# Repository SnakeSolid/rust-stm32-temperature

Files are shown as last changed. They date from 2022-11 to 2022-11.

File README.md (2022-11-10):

# Bluetooth Temperature Sensor

Read temperature, humidity and pressure from BME280 and write measurements to Bluetooth serial port. Serial output
example:

```
T: 23:87 C, P: 749.6 mmHg, H: 35.844%
T: 24:76 C, P: 749.6 mmHg, H: 34.101%
T: 24.70 C, P: 749.7 mmHg, H: 33.334%
```

Note: output rows are separated with `\n` new line sequence.

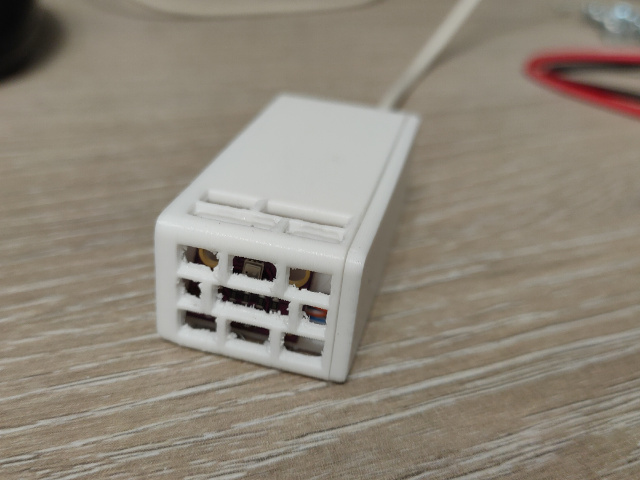
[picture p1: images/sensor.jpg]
Bluetooth sensor


### Wiring Diagram

Sensor BME280 use interface I2C2 (PA12, PA11), Bluetooth use interface USART2 (PA2, PA3). By default BME280 must be
available on address 0x76 (SDO connected to GND).

```
                                 STM32G030Fx (TSSOP20)
                        /-------------------------------------+
                      --| PB7/PB8           20PB3/PB4/PB5/PB6 |--
                      --| PB9/PC14-OSC32_IN   PA15/PA14-BOOT0 |--      to BME280
                      --| PC15-OSC32_OUT                 PA13 |--
                      --| VDD/VDDA                 PA12[PA10] |-- I2C2_SDA
                      --| VSS/VSSA                  PA11[PA9] |-- I2C2_SCL
                      --| NRST                PB0/PB1/PB2/PA8 |--
   to Bluetooth       --| PA0                             PA7 |--
                      --| PA1                             PA6 |--
            USART2_TX --| PA2                             PA5 |--
            USART2_RX --| PA3                             PA4 |--
                        +-------------------------------------+
```

### Build

By default cargo will use native build target. To build firmware for STM32G030 following command can be used:

```sh
cargo build --target thumbv6m-none-eabi --release
```

Command to connect to microcontroller using JTAG:

```sh
openocd -f openocd.cfg
```

Version of `openocd` utility must be greater or equals to `0.11.0`, earlier versions does not support STM32G030
microcontrollers. To flash and debug firmware use following command:

```sh
gdb-multiarch target/thumbv6m-none-eabi/release/stm32-bme280-temperature --command openocd.gdb
```

File `openocd.gdb` already contains commands to establish connection with `openocd`, enable semihosting, load firmware
and set breakpoints to `DefaultHandler` and `HardFault` handlers. After flashing firmware will be paused, command
`continue` will start firmware execution.

### License

Source code is primarily distributed under the terms of the MIT license. See LICENSE for details.

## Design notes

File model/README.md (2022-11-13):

# Content

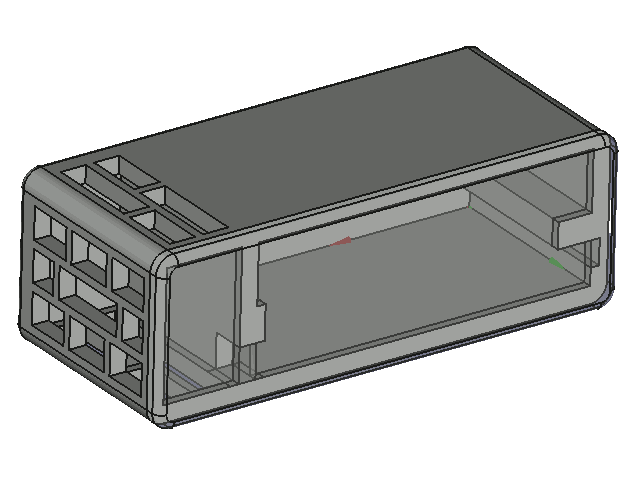
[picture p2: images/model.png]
Case model


* `temperature_sensor.FCStd` - FreeCAD case model with boxes for STM32G030, JDY-34 and BME boards;
* `temperature_sensor_body.stl` and `temperature_sensor_cap.stl` - meshes for case. Meshed are ready to import to
slicer.

This model created for development board with STM32G030F6P6 microcontroller, JDY-34 DIP board and BME280 6-PIN board.
All components can be placed in case from bottom to up side:

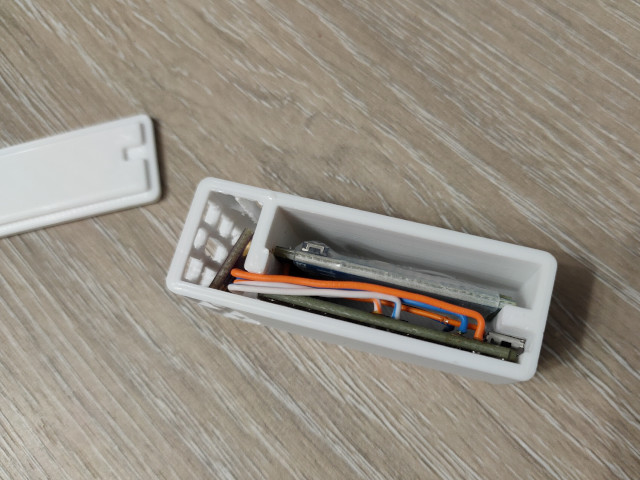
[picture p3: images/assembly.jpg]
Assembly example Wiring example


Components: STM32G030F6P6 development board in the bottom, JDY-34 board on the top, BME280 sensor board in the left
side.

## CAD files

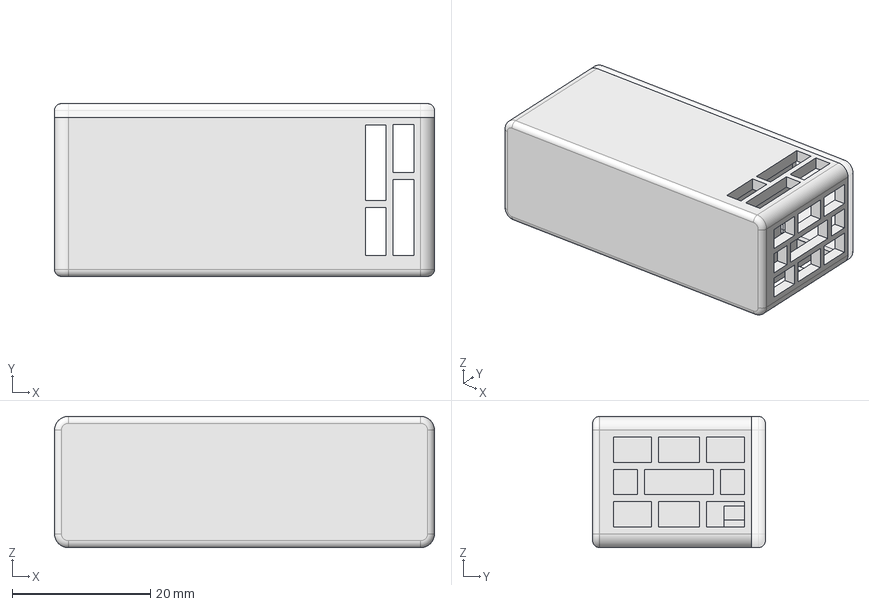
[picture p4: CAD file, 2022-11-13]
model/temperature_sensor.FCStd
55.0 x 25.0 x 19.0 mm
CaseBody
CaseCap

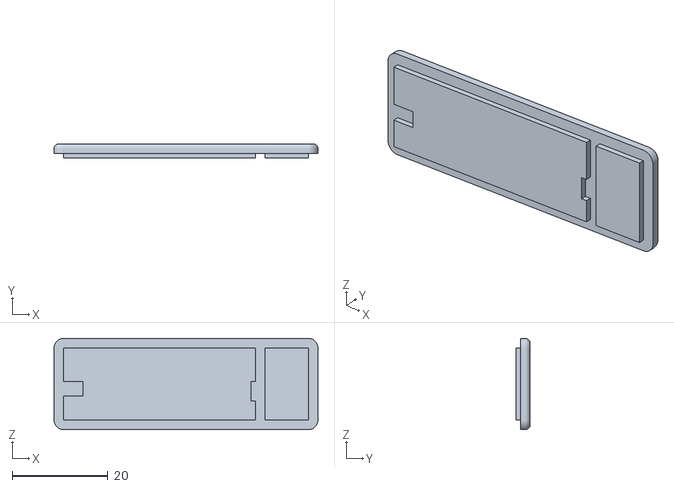
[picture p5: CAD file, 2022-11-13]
model/temperature_sensor_cap.stl
55.0 x 3.00 x 19.0

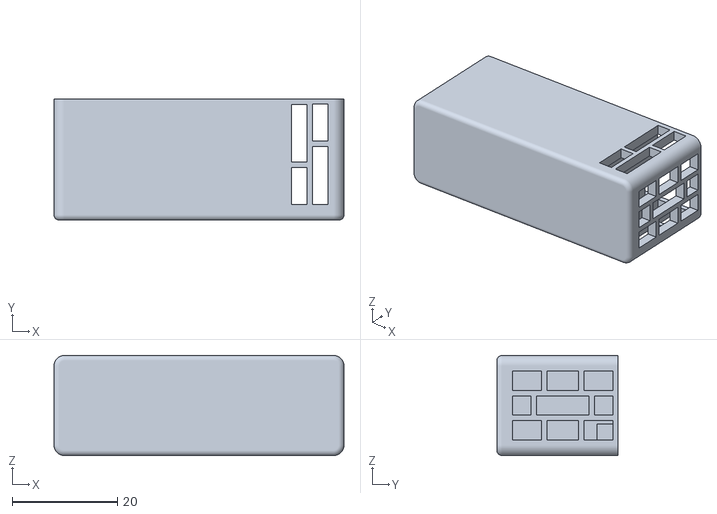
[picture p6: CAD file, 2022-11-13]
model/temperature_sensor_body.stl
55.0 x 23.0 x 19.0

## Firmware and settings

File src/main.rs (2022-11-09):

#![deny(unsafe_code)]
#![deny(warnings)]
#![no_main]
#![no_std]

use bme280::Bme280;
use bme280::HumidityExt;
use bme280::HumiditySampling;
use bme280::PressureExt;
use bme280::PressureSampling;
use bme280::SensorMode;
use bme280::TemperatireSampling;
use bme280::TemperatureExt;
use core::fmt::Write;
use core::panic::PanicInfo;
use cortex_m::asm::wfi;
use cortex_m::prelude::*;
use cortex_m_rtic_macros::app;
use stm32g0xx_hal::gpio::gpioa::PA11;
use stm32g0xx_hal::gpio::gpioa::PA12;
use stm32g0xx_hal::gpio::gpiob::PB0;
use stm32g0xx_hal::gpio::GpioExt;
use stm32g0xx_hal::gpio::OpenDrain;
use stm32g0xx_hal::gpio::Output;
use stm32g0xx_hal::gpio::PushPull;
use stm32g0xx_hal::i2c::Config as I2CConfig;
use stm32g0xx_hal::i2c::I2c;
use stm32g0xx_hal::i2c::I2cExt;
use stm32g0xx_hal::prelude::OutputPin;
use stm32g0xx_hal::prelude::PinState;
use stm32g0xx_hal::rcc::RccExt;
use stm32g0xx_hal::serial::BasicConfig;
use stm32g0xx_hal::serial::SerialExt;
use stm32g0xx_hal::serial::Tx;
use stm32g0xx_hal::stm32::I2C2;
use stm32g0xx_hal::stm32::TIM17;
use stm32g0xx_hal::stm32::USART2;
use stm32g0xx_hal::time::U32Ext;
use stm32g0xx_hal::timer::delay::DelayExt;
use stm32g0xx_hal::timer::Timer;
use stm32g0xx_hal::timer::TimerExt;

type Timer17 = Timer<TIM17>;

type LedPin = PB0<Output<PushPull>>;

type UsartTx = Tx<USART2, BasicConfig>;

type I2C = I2c<I2C2, PA12<Output<OpenDrain>>, PA11<Output<OpenDrain>>>;

#[app(device = stm32g0xx_hal::stm32, peripherals = true)]
mod app {
    use super::*;

    #[shared]
    struct Shared {}

    #[local]
    struct Local {
        timer: Timer17,
        led: LedPin,
        usart_tx: UsartTx,
        i2c: I2C,
        bme280: Bme280,
    }

    #[init]
    fn init(context: init::Context) -> (Shared, Local, init::Monotonics) {
        let mut rcc = context.device.RCC.constrain();
        let gpioa = context.device.GPIOA.split(&mut rcc);
        let gpiob = context.device.GPIOB.split(&mut rcc);
        let led = gpiob.pb0.into_push_pull_output();
        let tx = gpioa.pa2;
        let rx = gpioa.pa3;
        let sda = gpioa.pa12.into_open_drain_output_in_state(PinState::High);
        let scl = gpioa.pa11.into_open_drain_output_in_state(PinState::High);
        let (mut usart_tx, _usart_rx) = context
            .device
            .USART2
            .usart(
                tx,
                rx,
                BasicConfig::default().baudrate(9_600.bps()),
                &mut rcc,
            )
            .unwrap()
            .split();
        let mut i2c = context
            .device
            .I2C2
            .i2c(sda, scl, I2CConfig::new(400.khz()), &mut rcc);
        let bme280 = Bme280::address_low(&mut i2c).expect("Failed to initialize BME280 sensor");
        bme280
            .reset(&mut i2c)
            .expect("Failed to reset BME280 sensor");
        bme280
            .sampling(
                &mut i2c,
                HumiditySampling::Sampling16,
                TemperatireSampling::Sampling16,
                PressureSampling::Sampling16,
                SensorMode::Normal,
            )
            .expect("Failed to set sampling for BME280 sensor");

        let mut delay = context.device.TIM17.delay(&mut rcc);
        delay.delay(100.ms()); // Wait for BME280 first measurement.

        let mut timer = delay.release().timer(&mut rcc);
        timer.start(60.seconds());
        timer.listen();

        let _ = writeln!(usart_tx, "Ready.");

        (
            Shared {},
            Local {
                timer,
                led,
                usart_tx,
                i2c,
                bme280,
            },
            init::Monotonics(),
        )
    }

    #[idle(local = [ led, usart_tx, i2c, bme280 ])]
    fn idle(context: idle::Context) -> ! {
        loop {
            let _ = context.local.led.set_low();
            let temperature = context
                .local
                .bme280
                .temperature(context.local.i2c)
                .expect("Failed to read temperature")
                .c();
            let pressure = context
                .local
                .bme280
                .pressure(context.local.i2c)
                .expect("Failed to read pressure")
                .mmhg();
            let humidity = context
                .local
                .bme280
                .humidity(context.local.i2c)
                .expect("Failed to read humidity")
                .percent();
            let _ = writeln!(
                context.local.usart_tx,
                "T: {}.{:02} C, P: {}.{:01} mmHg, H: {}.{:03}%",
                temperature.0, temperature.1, pressure.0, pressure.1, humidity.0, humidity.1,
            );
            let _ = context.local.led.set_high();

            wfi();
        }
    }

    #[task(binds = TIM17, local = [ timer ])]
    fn timer_tick(context: timer_tick::Context) {
        context.local.timer.clear_irq();
    }
}

#[panic_handler]
fn panic(_info: &PanicInfo) -> ! {
    loop {}
}

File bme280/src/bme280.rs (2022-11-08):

use embedded_hal::blocking::i2c::Write;
use embedded_hal::blocking::i2c::WriteRead;

const BME280_ADDRESS_LOW: u8 = 0x76;
const BME280_ADDRESS_HIGH: u8 = 0x77;
const BME280_RESET_VALUE: u8 = 0xB6;

const REGISTER_DIG_T1: u8 = 0x88;
const REGISTER_DIG_T2: u8 = 0x8A;
const REGISTER_DIG_T3: u8 = 0x8C;
const REGISTER_DIG_P1: u8 = 0x8E;
const REGISTER_DIG_P2: u8 = 0x90;
const REGISTER_DIG_P3: u8 = 0x92;
const REGISTER_DIG_P4: u8 = 0x94;
const REGISTER_DIG_P5: u8 = 0x96;
const REGISTER_DIG_P6: u8 = 0x98;
const REGISTER_DIG_P7: u8 = 0x9A;
const REGISTER_DIG_P8: u8 = 0x9C;
const REGISTER_DIG_P9: u8 = 0x9E;
const REGISTER_DIG_H1: u8 = 0xA1;
const REGISTER_DIG_H2: u8 = 0xE1;
const REGISTER_DIG_H3: u8 = 0xE3;
const REGISTER_DIG_H4: u8 = 0xE4;
const REGISTER_DIG_H5: u8 = 0xE5;
const REGISTER_DIG_H6: u8 = 0xE7;

const REGISTER_ID: u8 = 0xD0;
const REGISTER_RESET: u8 = 0xE0;
const REGISTER_STATUS: u8 = 0xF3;
const REGISTER_PRESSURE: u8 = 0xF7;
const REGISTER_TEMPERATURE: u8 = 0xFA;
const REGISTER_HUMIDITY: u8 = 0xFD;
const REGISTER_HUMIDITY_CONTROL: u8 = 0xF2;
const REGISTER_MEASUREMENT_CONTROL: u8 = 0xF4;

#[derive(Debug)]
#[repr(u8)]
pub enum HumiditySampling {
    Skipped = 0b00000_000,
    Sampling1 = 0b00000_001,
    Sampling2 = 0b00000_010,
    Sampling4 = 0b00000_011,
    Sampling8 = 0b00000_100,
    Sampling16 = 0b00000_101,
}

#[derive(Debug)]
#[repr(u8)]
pub enum TemperatireSampling {
    Skipped = 0b000_000_00,
    Sampling1 = 0b001_000_00,
    Sampling2 = 0b010_000_00,
    Sampling4 = 0b011_000_00,
    Sampling8 = 0b100_000_00,
    Sampling16 = 0b101_000_00,
}

#[derive(Debug)]
#[repr(u8)]
pub enum PressureSampling {
    Skipped = 0b000_000_00,
    Sampling1 = 0b000_001_00,
    Sampling2 = 0b000_010_00,
    Sampling4 = 0b000_011_00,
    Sampling8 = 0b000_100_00,
    Sampling16 = 0b000_101_00,
}

#[derive(Debug)]
#[repr(u8)]
pub enum SensorMode {
    Sleep = 0b000000_00,
    Foeced = 0b000000_01,
    Normal = 0b000000_11,
}

#[derive(Debug)]
pub struct BmeStatus {
    measuring: bool,
    im_update: bool,
}

impl BmeStatus {
    pub fn new(measuring: bool, im_update: bool) -> BmeStatus {
        BmeStatus {
            measuring,
            im_update,
        }
    }

    pub fn measuring(&self) -> bool {
        self.measuring
    }

    pub fn im_update(&self) -> bool {
        self.im_update
    }
}

#[derive(Debug)]
pub struct Bme280 {
    address: u8,
    temprerature_fine: i32,
    compensation_data: CompensationData,
}

impl Bme280 {
    pub fn address_low<I2C>(i2c: &mut I2C) -> Result<Bme280, I2C::Error>
    where
        I2C: WriteRead,
    {
        let address = BME280_ADDRESS_LOW;
        let mut buffer = [0; 1];

        i2c.write_read(address, &[REGISTER_ID], &mut buffer)?;

        let compensation_data = CompensationData::read(i2c, address)?;

        Ok(Bme280 {
            address,
            temprerature_fine: 0,
            compensation_data,
        })
    }

    pub fn address_high<I2C>(i2c: &mut I2C) -> Result<Bme280, I2C::Error>
    where
        I2C: WriteRead,
    {
        let address = BME280_ADDRESS_HIGH;
        let compensation_data = CompensationData::read(i2c, address)?;

        Ok(Bme280 {
            address,
            temprerature_fine: 0,
            compensation_data,
        })
    }

    pub fn id<I2C>(&self, i2c: &mut I2C) -> Result<u8, I2C::Error>
    where
        I2C: WriteRead,
    {
        let mut buffer = [0; 1];

        i2c.write_read(self.address, &[REGISTER_ID], &mut buffer)?;

        Ok(buffer[0])
    }

    pub fn reset<I2C>(&self, i2c: &mut I2C) -> Result<(), I2C::Error>
    where
        I2C: Write,
    {
        i2c.write(self.address, &[REGISTER_RESET, BME280_RESET_VALUE])?;

        Ok(())
    }

    pub fn status<I2C>(&self, i2c: &mut I2C) -> Result<BmeStatus, I2C::Error>
    where
        I2C: WriteRead,
    {
        let mut buffer = [0; 1];

        i2c.write_read(self.address, &[REGISTER_STATUS], &mut buffer)?;

        Ok(BmeStatus::new(
            buffer[0] & 0b0000_1000 == 0,
            buffer[0] & 0b0000_0001 == 0,
        ))
    }

    pub fn sampling<I2C>(
        &self,
        i2c: &mut I2C,
        humidity: HumiditySampling,
        temperatire: TemperatireSampling,
        pressure: PressureSampling,
        mode: SensorMode,
    ) -> Result<(), I2C::Error>
    where
        I2C: Write,
    {
        i2c.write(self.address, &[REGISTER_HUMIDITY_CONTROL, humidity as u8])?;
        i2c.write(
            self.address,
            &[
                REGISTER_MEASUREMENT_CONTROL,
                temperatire as u8 | pressure as u8 | mode as u8,
            ],
        )?;

        Ok(())
    }

    pub fn temperature<I2C>(&mut self, i2c: &mut I2C) -> Result<i32, I2C::Error>
    where
        I2C: WriteRead,
    {
        let mut buffer = [0; 3];
        i2c.write_read(self.address, &[REGISTER_TEMPERATURE], &mut buffer)?;

        let adc_temperature =
            ((buffer[0] as i32) << 12) | ((buffer[1] as i32) << 4) | ((buffer[2] as i32) >> 4);

        if adc_temperature == 0x080000 {
            return Ok(0);
        }

        let dig_t1 = self.compensation_data.dig_t1 as i32;
        let dig_t2 = self.compensation_data.dig_t2 as i32;
        let dig_t3 = self.compensation_data.dig_t3 as i32;

        let var1 = (((adc_temperature >> 3) - (dig_t1 << 1)) * dig_t2) >> 11;
        let var2 = (((((adc_temperature >> 4) - dig_t1) * ((adc_temperature >> 4) - dig_t1))
            >> 12)
            * dig_t3)
            >> 14;

        self.temprerature_fine = var1 + var2;

        let temperature = (self.temprerature_fine * 5 + 128) >> 8;

        Ok(temperature)
    }

    pub fn pressure<I2C>(&self, i2c: &mut I2C) -> Result<u32, I2C::Error>
    where
        I2C: WriteRead,
    {
        let mut buffer = [0; 3];
        i2c.write_read(self.address, &[REGISTER_PRESSURE], &mut buffer)?;

        let adc_pressure =
            ((buffer[0] as i32) << 12) | ((buffer[1] as i32) << 4) | ((buffer[2] as i32) >> 4);

        if adc_pressure == 0x080000 {
            return Ok(0);
        }

        let dig_p1 = self.compensation_data.dig_p1 as i64;
        let dig_p2 = self.compensation_data.dig_p2 as i64;
        let dig_p3 = self.compensation_data.dig_p3 as i64;
        let dig_p4 = self.compensation_data.dig_p4 as i64;
        let dig_p5 = self.compensation_data.dig_p5 as i64;
        let dig_p6 = self.compensation_data.dig_p6 as i64;

        let var1 = self.temprerature_fine as i64 - 128000;
        let var2 = var1 * var1 * dig_p6;
        let var2 = var2 + ((var1 * dig_p5) << 17);
        let var2 = var2 + ((dig_p4) << 35);
        let var1 = ((var1 * var1 * dig_p3) >> 8) + ((var1 * dig_p2) << 12);
        let var1 = ((1 << 47) + var1) * (dig_p1) >> 33;

        if var1 == 0 {
            return Ok(0); // avoid exception caused by division by zero
        }
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

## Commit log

2022-11-08 use rtic for interrupt handling
2022-11-08 fixed function names, wait for bme280 initialization
    [bme280.rs, main.rs]
2022-11-09 fixed example, updated device.x file
2022-11-09 removed carriage return from output
2022-11-10 simple case model for sensor
    [temperature_sensor.FCStd, temperature_sensor_body.stl, temperature_sensor_cap.stl]
2022-11-10 case assembly example
2022-11-10 assembled sensor, fixed readme file
2022-11-13 move sensor to sepereted section
    [temperature_sensor.FCStd, temperature_sensor_body.stl, temperature_sensor_cap.stl]
